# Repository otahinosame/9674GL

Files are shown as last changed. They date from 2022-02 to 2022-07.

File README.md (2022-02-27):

# 9674GL
GL516 Case Compatible Keyboard
GL516ケース対応キーボード

9674GL keyboard a.k.a. wagatatami
9674GL、またの名を「我が畳」。

FI1ZKy6aAAA8mE0

EzhHw1ZVIAMwrmL

hash tag: #9674GL

## コンセプト

* 40%キーボード感覚で使える65%キーボード。
* 96キーレイアウトを65%サイズ（キー数は74キー）に凝縮。

* 右端の5行3列のエリアは、数字入力のためのテンキー、レイヤーを使わないカーソル移動のためのナビゲーションクラスタ、40%配列に納まりきらない記号類など、様々な用途に合わせて自由に使える。
* 気分や作業内容によってキーキャップとキーマップを取り替えることで、かゆいところに手が届く自分だけの相棒になります。

## 配列のこだわり

* 分割スペースバーとその両サイドを左右対象にすることで、親指を起点とした操作がしやすい配列。
* 右下最下段を1uキー5個にすることで、好きな位置にアローキーを配置できる。
* キーキャップはよくあるBaseキットでだいたい揃うので、キーキャップの選択肢が豊富。（2uが3個必要なのと、Enterキーが1.25uなのでキーキャップの選択時は要注意）

## ビルドガイド

サリチル酸さん著の共通ビルドガイドを参考に組み立ててください。

GL516 互換PCB共通ビルドガイド
https://zenn.dev/salicylic_acid3/books/gl516_build_guide

### キットの内容物

| 項目 | 数量 |
| --- | ---- |
| PCB (ダイオード、ソケット実装済み) | 1 |
| スイッチプレート | 1 |
| ピンソケット | 2 |

### キット以外で必要なもの

| 項目 | 数量 |
| --- | ---- |
| GL516ケースと付属品一式 | 1 |
| Pro Micro | 1|
| ピンヘッダ |2 |
| MX互換スイッチ | 74 |
| MX互換キーキャッップ | 74 |
| MX互換スタビライザー（2u） | 3 |

### コンスルー同梱版の組み立て方

ピンヘッダの代わりに、コンスルーをPro Microにはんだ付けします。
* コンスルーをPCBに差し込みます
* コンスルーの反対側にPro Microを差し込みます
* Pro Microとコンスルーをはんだ付けします

### デコレーションプレート

BOOTHで購入いただくと、デコレーションプレートのカットデータがダウンロードできます。
また、遊舎工房のアクリルカットサービスに登録される予定のGL516汎用デコレーションプレートを注文することもできます。

## 入手先

BOOTHにて販売予定です。
https://otahinosame.booth.pm/items/3636926

## 謝辞

サリチル酸さん（ https://github.com/Salicylic-acid3 ）には、テンプレートの提供、設計データのレビュー、製造・頒布のサポートなど全面的に開発を助けていただきました。ありがとうございます。

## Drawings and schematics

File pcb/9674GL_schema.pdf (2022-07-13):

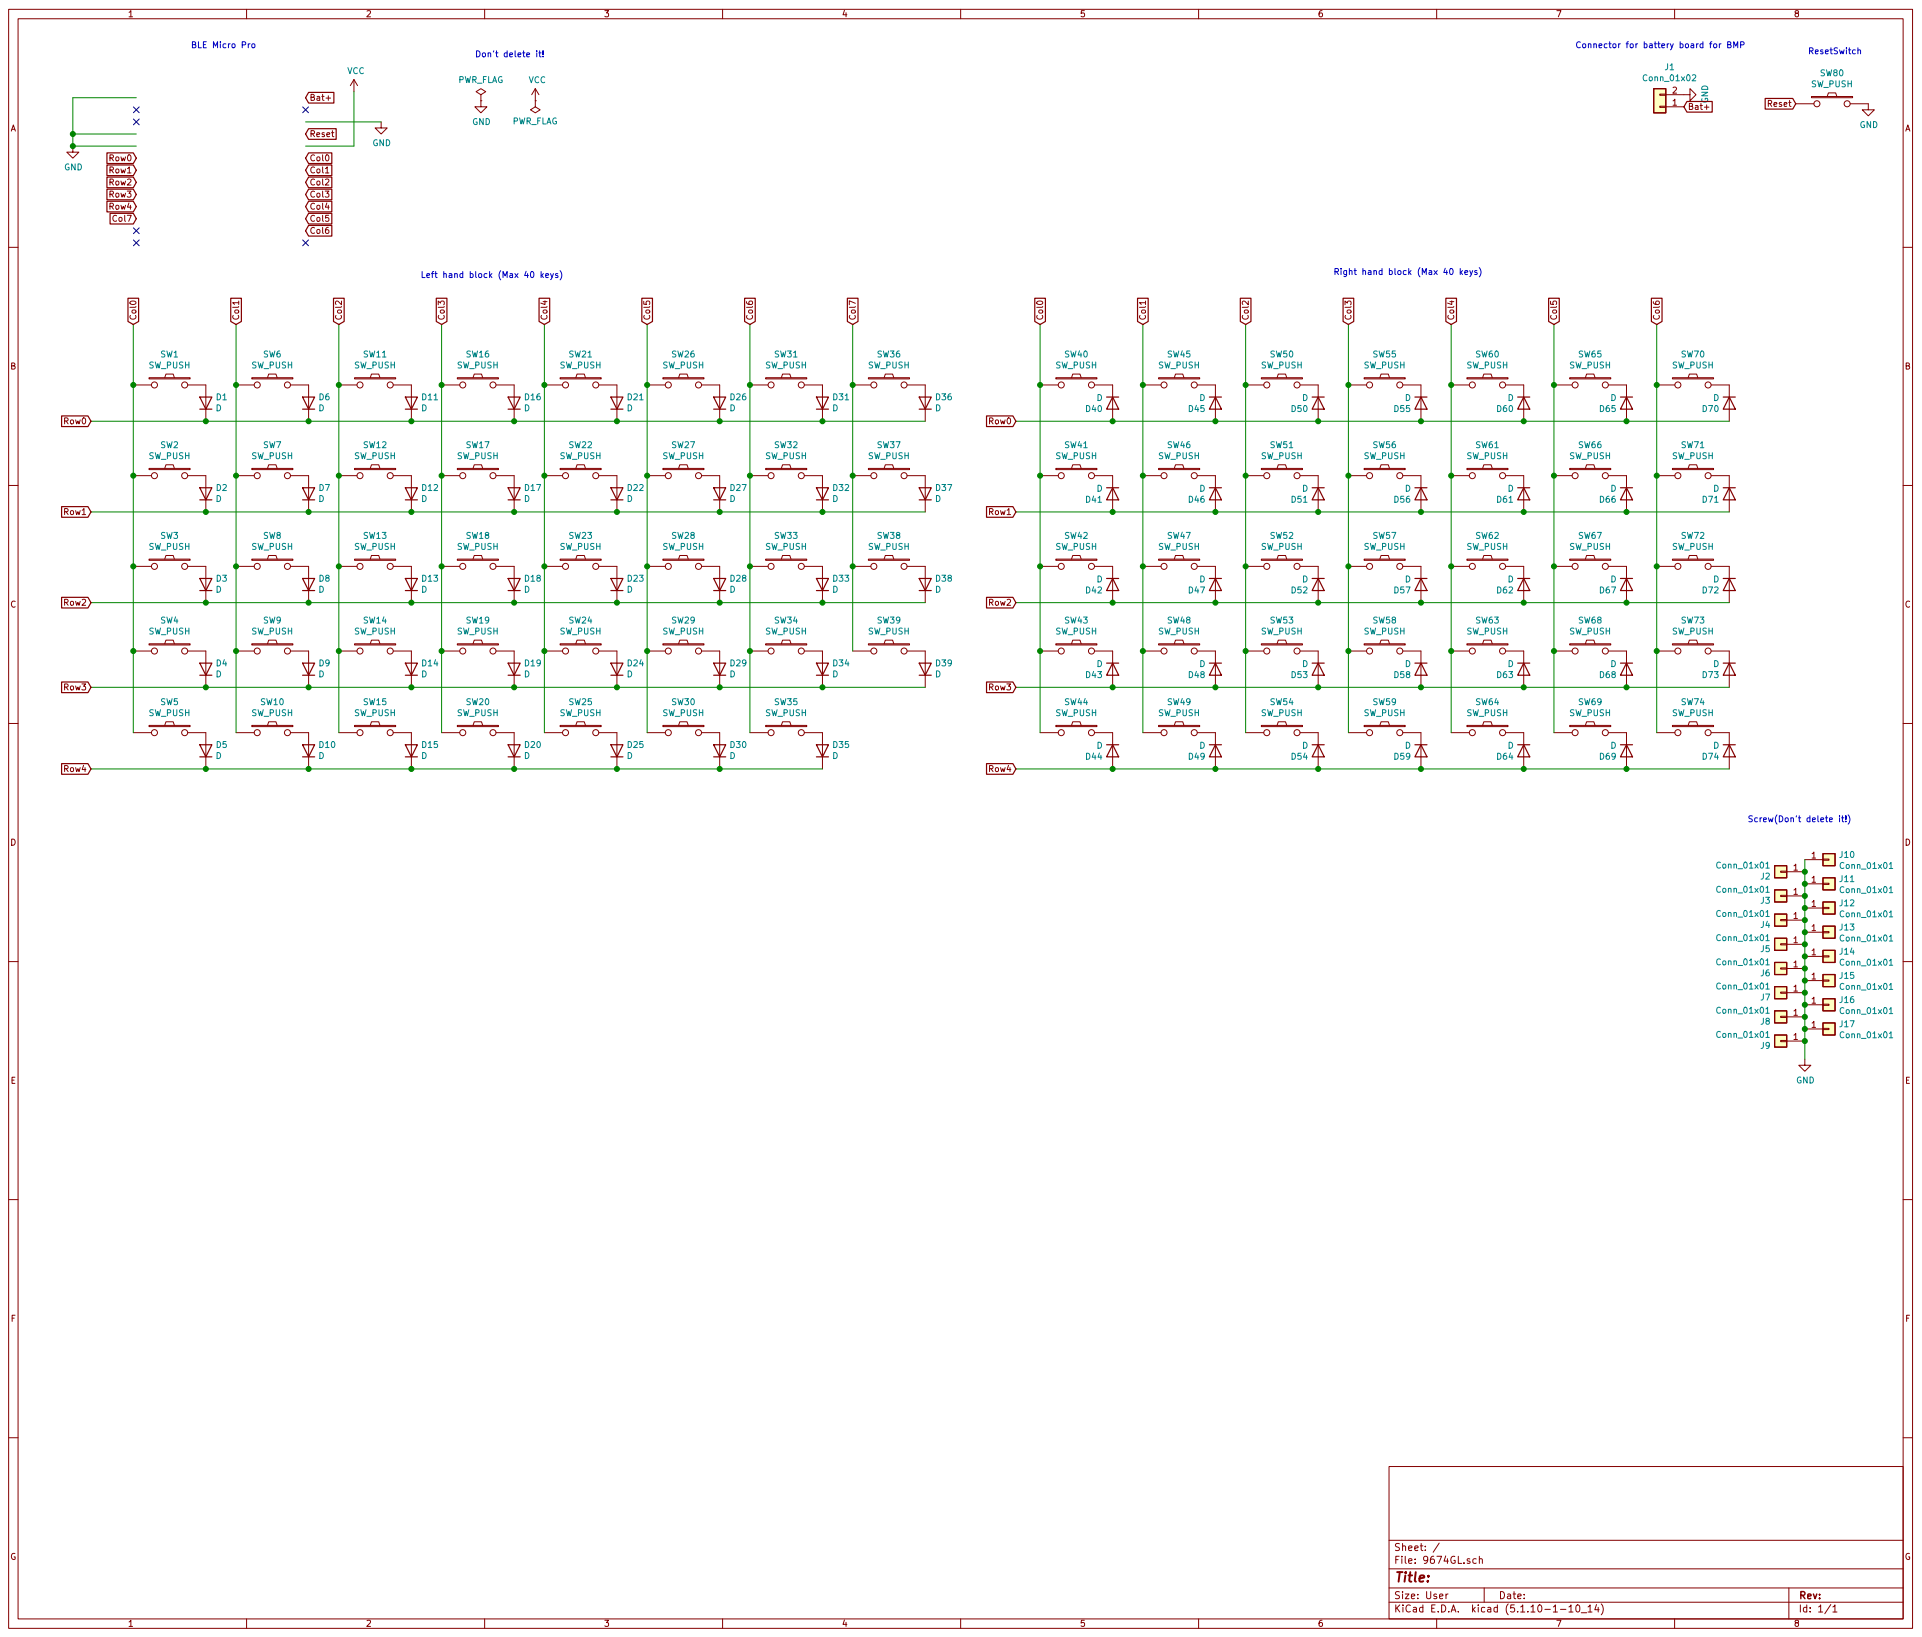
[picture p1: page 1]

Screw(Don't delete it!)

Id: 1/1 Title: File: 9674GL.sch Sheet: /

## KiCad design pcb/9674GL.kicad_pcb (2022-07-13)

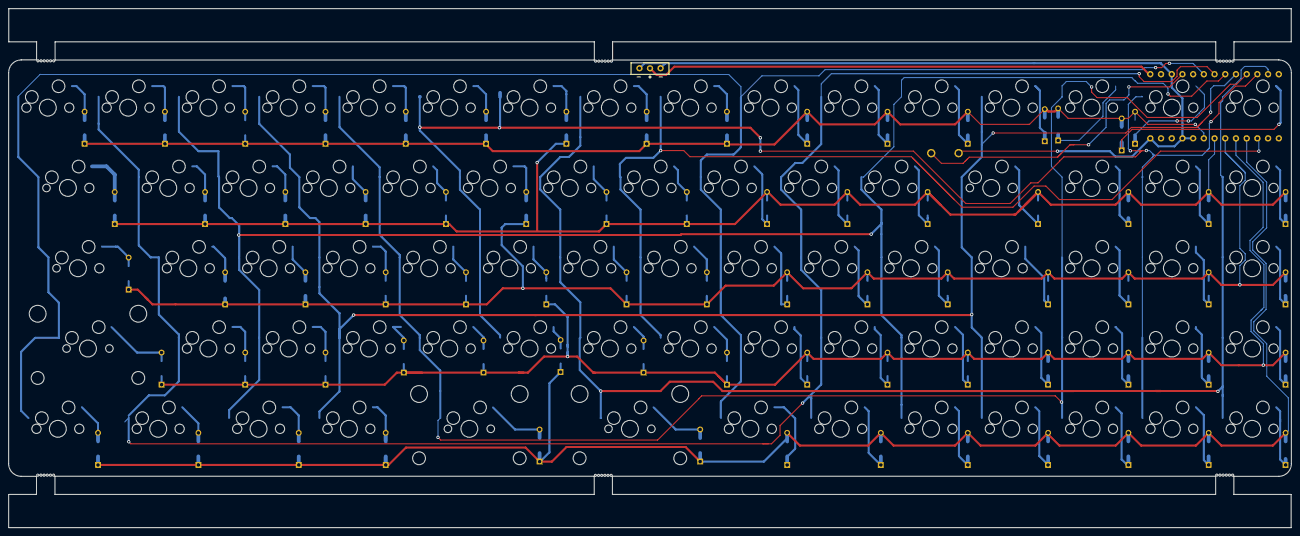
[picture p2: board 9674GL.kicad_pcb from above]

Board: 2 copper layers, 304.4 x 123.1 mm, 157 parts (1 on the bottom side), 90 nets.

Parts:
D1, D2, D3, D4, D5, D6, D7, D8, D9, D10, D11, D12, D13, D14, D15, D16, D17, D18, D19, D20, D21, D22, D23, D24, D25, D26, D27, D28, D29, D30, D31, D32, D33, D34, D35, D36, D37, D38, D39, D40, D41, D42, D43, D44, D45, D46, D47, D48, D49, D50, D51, D52, D53, D54, D55, D56, D57, D58, D59, D60, D61, D62, D63, D64, D65, D66, D67, D68, D69, D70, D71, D72, D73, D74: D; Diode_TH_SMD
J1: Conn_01x02; Battery_XH2.5_GL_PCB
Ref**: Val**; Mouse_Bite_Hole
Ref**#2, Ref**#3, Ref**#4, Ref**#5, Ref**#6: Val**; Mouse_Bite_Hole
SW1, SW6, SW7, SW8, SW9, SW11, SW12, SW13, SW14, SW16, SW17, SW18, SW19, SW20, SW21, SW22, SW23, SW24, SW26, SW27, SW28, SW29, SW30, SW31, SW32, SW33, SW34, SW36, SW37, SW38, SW39, SW40, SW41, SW42, SW43, SW44, SW45, SW46, SW47, SW48, SW50, SW51, SW52, SW53, SW54, SW55, SW58, SW59, SW60, SW61, SW62, SW63, SW64, SW66, SW67, SW68, SW69, SW71, SW72, SW73, SW74: SW_PUSH; CherryMX_Hotswap_1.0u
SW2, SW56: SW_PUSH; CherryMX_Hotswap_1.5u
SW3: SW_PUSH; CherryMX_Hotswap_1.75u
SW4, SW25, SW35: SW_PUSH; CherryMX_Hotswap_2u_Rev
SW5, SW10, SW15, SW49, SW57: SW_PUSH; CherryMX_Hotswap_1.25u
SW65, SW70: SW_PUSH; CherryMX_Hotswap_1.0u_Small1
SW80: SW_PUSH; ResetSW
U1: BLEMicroPro; Micon_BMP_GL

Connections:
Bat+: J1.1, U1.25
Col0: SW1.1, SW2.1, SW3.1, SW4.1, SW5.1, SW40.1, SW41.1, SW42.1, SW43.1, SW44.1, U1.20
Col1: SW6.1, SW7.1, SW8.1, SW9.1, SW10.1, SW45.1, SW46.1, SW47.1, SW48.1, SW49.1, U1.19
Col2: SW11.1, SW12.1, SW13.1, SW14.1, SW15.1, SW50.1, SW51.1, SW52.1, SW53.1, SW54.1, U1.18
Col3: SW16.1, SW17.1, SW18.1, SW19.1, SW20.1, SW55.1, SW56.1, SW57.1, SW58.1, SW59.1, U1.17
Col4: SW21.1, SW22.1, SW23.1, SW24.1, SW25.1, SW60.1, SW61.1, SW62.1, SW63.1, SW64.1, U1.16
Col5: SW26.1, SW27.1, SW28.1, SW29.1, SW30.1, SW65.1, SW66.1, SW67.1, SW68.1, SW69.1, U1.15
Col6: SW31.1, SW32.1, SW33.1, SW34.1, SW35.1, SW70.1, SW71.1, SW72.1, SW73.1, SW74.1, U1.14
Col7: SW36.1, SW37.1, SW38.1, SW39.1, U1.10
GND: J1.2, SW80.2, U1.3, U1.4, U1.23, U1.26
unnamed: D1.2, SW1.2
unnamed: D2.2, SW2.2
unnamed: D3.2, SW3.2
unnamed: D4.2, SW4.2
unnamed: D5.2, SW5.2
unnamed: D6.2, SW6.2
unnamed: D7.2, SW7.2
unnamed: D8.2, SW8.2
unnamed: D9.2, SW9.2
unnamed: D10.2, SW10.2
unnamed: D11.2, SW11.2
unnamed: D12.2, SW12.2
unnamed: D13.2, SW13.2
unnamed: D14.2, SW14.2
unnamed: D15.2, SW15.2
unnamed: D16.2, SW16.2
unnamed: D17.2, SW17.2
unnamed: D18.2, SW18.2
unnamed: D19.2, SW19.2
unnamed: D20.2, SW20.2
unnamed: D21.2, SW21.2
unnamed: D22.2, SW22.2
unnamed: D23.2, SW23.2
unnamed: D24.2, SW24.2
unnamed: D25.2, SW25.2
unnamed: D26.2, SW26.2
unnamed: D27.2, SW27.2
unnamed: D28.2, SW28.2
unnamed: D29.2, SW29.2
unnamed: D30.2, SW30.2
unnamed: D31.2, SW31.2
unnamed: D32.2, SW32.2
unnamed: D33.2, SW33.2
unnamed: D34.2, SW34.2
unnamed: D35.2, SW35.2
unnamed: D36.2, SW36.2
unnamed: D37.2, SW37.2
unnamed: D38.2, SW38.2
unnamed: D39.2, SW39.2
unnamed: D40.1, SW40.2
unnamed: D41.1, SW41.2
unnamed: D42.1, SW42.2
unnamed: D43.1, SW43.2
unnamed: D44.1, SW44.2
unnamed: D45.1, SW45.2
unnamed: D46.1, SW46.2
unnamed: D47.1, SW47.2
unnamed: D48.1, SW48.2
unnamed: D49.1, SW49.2
unnamed: D50.1, SW50.2
unnamed: D51.1, SW51.2
unnamed: D52.1, SW52.2
unnamed: D53.1, SW53.2
unnamed: D54.1, SW54.2
unnamed: D55.1, SW55.2
unnamed: D56.1, SW56.2
unnamed: D57.1, SW57.2
unnamed: D58.1, SW58.2
unnamed: D59.1, SW59.2
unnamed: D60.1, SW60.2
unnamed: D61.1, SW61.2
unnamed: D62.1, SW62.2
unnamed: D63.1, SW63.2
unnamed: D64.1, SW64.2
unnamed: D65.1, SW65.2
unnamed: D66.1, SW66.2
unnamed: D67.1, SW67.2
unnamed: D68.1, SW68.2
unnamed: D69.1, SW69.2
unnamed: D70.1, SW70.2
unnamed: D71.1, SW71.2
unnamed: D72.1, SW72.2
unnamed: D73.1, SW73.2
unnamed: D74.1, SW74.2
Reset: SW80.1, U1.22
Row0: D1.1, D6.1, D11.1, D16.1, D21.1, D26.1, D31.1, D36.1, D40.2, D45.2, D50.2, D55.2, D60.2, D65.2, D70.2, U1.5
Row1: D2.1, D7.1, D12.1, D17.1, D22.1, D27.1, D32.1, D37.1, D41.2, D46.2, D51.2, D56.2, D61.2, D66.2, D71.2, U1.6
Row2: D3.1, D8.1, D13.1, D18.1, D23.1, D28.1, D33.1, D38.1, D42.2, D47.2, D52.2, D57.2, D62.2, D67.2, D72.2, U1.7
Row3: D4.1, D9.1, D14.1, D19.1, D24.1, D29.1, D34.1, D39.1, D43.2, D48.2, D53.2, D58.2, D63.2, D68.2, D73.2, U1.8
Row4: D5.1, D10.1, D15.1, D20.1, D25.1, D30.1, D35.1, D44.2, D49.2, D54.2, D59.2, D64.2, D69.2, D74.2, U1.9

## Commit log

2022-07-13 Create pcb
2022-07-13 add pcb and plate
    [9674GL-B_Cu.gbl, 9674GL-B_Mask.gbs, 9674GL-B_SilkS.gbo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]
